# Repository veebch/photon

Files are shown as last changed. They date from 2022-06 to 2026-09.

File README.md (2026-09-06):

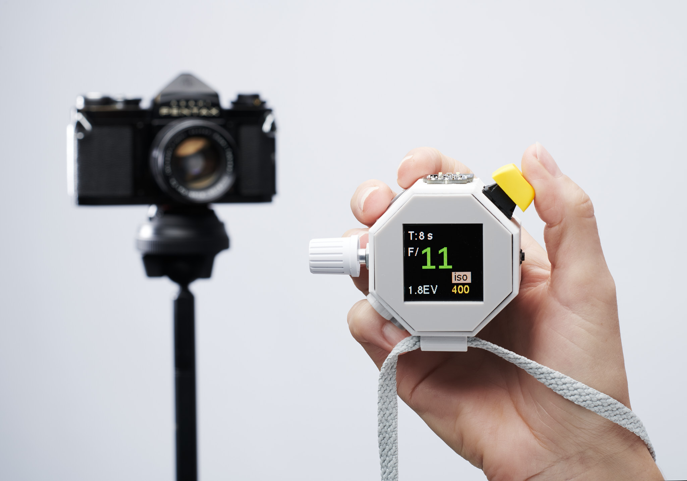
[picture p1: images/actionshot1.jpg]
Action Shot


 

# Photon: an open-source incident light meter 

Photon reproduces the some of the functionality of more expensive tools, using a few inexpensive/readily available parts. Currently it measures ambient light brightness, as well as the red, green and blue components of the light, which might allow White Balance readings in future iterations.

There is soldering involved, but don't let that put you off, [it's easy](https://www.youtube.com/watch?v=Qps9woUGkvI).

COMING SOON: Custom sensor with [Flash Mode](https://www.veeb.ch/projects/flash-aaahhh-ahhhhhh)

## Background

An incident light-meter can be an essential tool in photography (especially film photography with old cameras). The sophisticated computation baked-in to modern cameras devotes a lot of effort guessing 'how much light is falling on the subject?". If you have the option of getting to the subject and taking a reading, no guessing is required and everything becomes a lot easier. A more in-depth description in the video below:

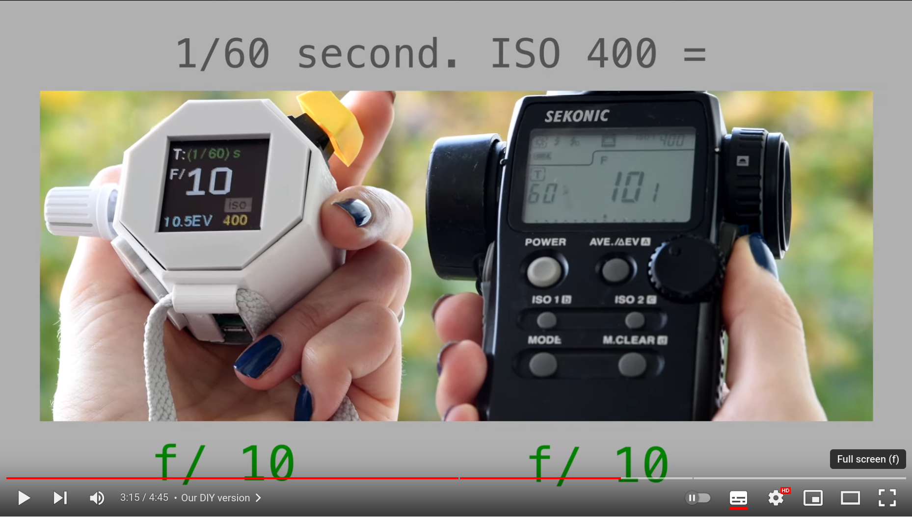
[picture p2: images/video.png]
IMAGE ALT TEXT HERE (https://www.youtube.com/watch?v=xju3yHBka7Q)


## Components

- Raspberry Pi Pico           (or Pico Lipo, so you don't need to add the separate power shim)
- OLED Screen                 ([Waveshare 128x128 full colour](https://www.amazon.de/-/en/gp/product/B07DB5YFGW/ref=ppx_yo_dt_b_asin_title_o08_s00?ie=UTF8&psc=1))
- LiPo Power shim             ([Pimoroni LiPo Pico shim](https://shop.pimoroni.com/products/pico-lipo-shim?variant=32369543086163) - only if you a using a Pi Pico)
- Rotary encoder              (adjust settings and change priority mode) ([example](https://www.reichelt.com/ch/de/entwicklerboards-drehwinkel-encoder-ky-040-debo-encoder-p282545.html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))
- Two momentary switches      (1x [keyboard switch](https://keyboardsexpert.com/types-of-keyboard-switches/) and 1x **6x6mm** microswitch to measure light and set iso adjust mode respectively)
- Light Sensor                ([Pimoroni BH1745](https://shop.pimoroni.com/products/bh1745-luminance-and-colour-sensor-breakout?variant=12767599755347))             
- LiPo/LiIon battery

# Assembly

## Hardware

If you're using one, solder the power shim to the pico following the Pimoroni instructions. Connect the Lipo/LiIon battery to the shim. 

Then connect the rest of the components to the GPIO pins as described in the tables below. (**VCC and GND are also connected to the pico for all except the switch**) 

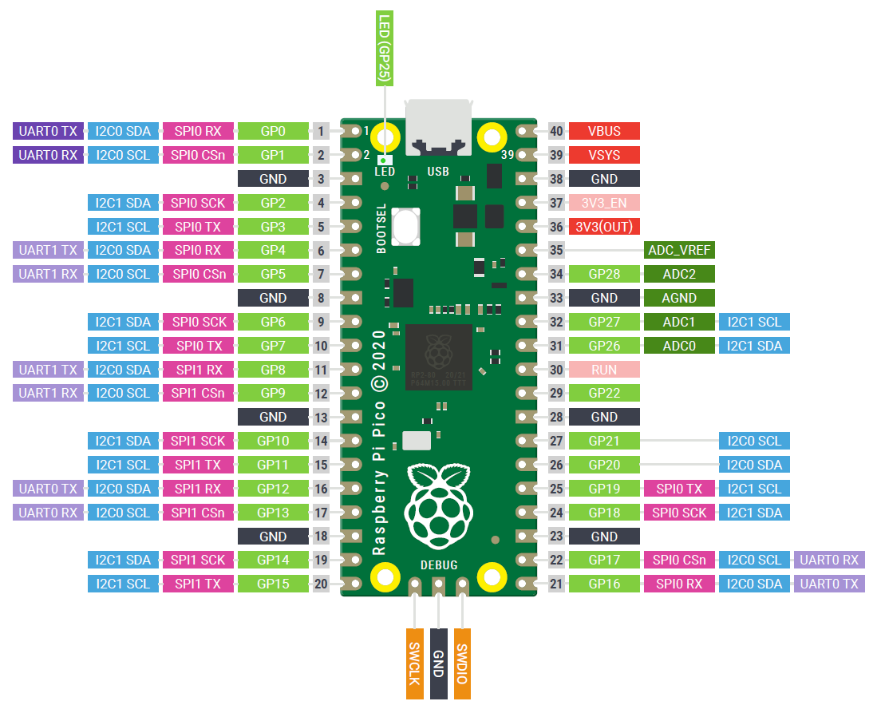
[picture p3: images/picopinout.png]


### Light Sensor

| [Pico GPIO](https://www.elektronik-kompendium.de/sites/raspberry-pi/bilder/raspberry-pi-pico-gpio.png) | BH1745 |
|---|---|
| 4 | SDA  |
| 5 | SCL  |

### OLED

| [Pico GPIO](https://www.elektronik-kompendium.de/sites/raspberry-pi/bilder/raspberry-pi-pico-gpio.png) | OLED | Pin Number |
|---|---|---|
| 19 | DIN/MOSI  | 25 | 
| 18 | CLK/SCK  | 24 |
| 17 | CS  |  22 |
| 20 | DC  |  26 |
| 21 | RST  | 27  |

### Rotary Encoder:

| [Pico GPIO](https://www.elektronik-kompendium.de/sites/raspberry-pi/bilder/raspberry-pi-pico-gpio.png) | Rotary Encoder |
|---|---|
| 6 | CLK |
| 7 | DT |
| 8 | SW |

### The Two Switches

Connect one end of the switch to GND, and the other to:

| [Pico GPIO](https://www.elektronik-kompendium.de/sites/raspberry-pi/bilder/raspberry-pi-pico-gpio.png) | Switches |
|---|---|
| 15 | Measure (Keyboard Switch) |
| 22 | ISO (6x6mm switch)  |

### Enclosure Assembly

Once you've tested that things are working, squeeze the parts into an enclosure. If you have access to a 3D printer, there are stl files in the [cases](/cases) directory.

## Software

Download a `uf2` image from the [Pimoroni github repository](https://github.com/pimoroni/pimoroni-pico/releases) and install it on the Pico according to the instructions. You need to use the Pimoroni image to be able to use Pimoroni drivers for the light sensor.

Clone this repository to your computer using the commands (from a terminal):

```
cd ~
git clone https://github.com/veebch/photon.git
cd photon
```

Connect the Pico with a data-capable USB cable in normal MicroPython mode. On macOS or Linux, prepare the local upload environment once:

```sh
python3 -m venv .venv
.venv/bin/python -m pip install -r requirements-dev.txt
```

Upload Photon and restart the Pico:

```sh
.venv/bin/python tools/upload_pico.py
```

The uploader normally detects the only connected MicroPython board. If more than one serial device is connected, select the Pico explicitly:

```sh
.venv/bin/python -m mpremote devs
.venv/bin/python tools/upload_pico.py --port /dev/cu.usbmodem101
```

Linux port names commonly look like `/dev/ttyACM0`. Close Thonny, serial monitors, and other programs using the Pico before uploading. To inspect the commands without changing the board, add `--dry-run`.

All required files are copied to the Pico, which is then soft-reset so `main.py` starts. It will also autorun after later power cycles.

## Using the Light Meter 

A tutorial on getting the most out of your new meter is in the [docs](/docs) section. 

## Press

### German 
- https://heise.de/-9611848

## Contributing to the code

If you look at this, find it interesting, and know you can make it better then please fork the repository and use a feature branch. Pull requests are welcome and encouraged... in a nutshell:

1.    Fork it
2.    Create your feature branch (git checkout -b feature/fooBar)
3.    Commit your changes (git commit -am 'Add some fooBar')
4.    Push to the branch (git push origin feature/fooBar)
5.    Create a new Pull Request

If that all looks a bit too programmy, and if you have some photography expertise that you think could be embedded in the code then raise an issue on GitHub or [contact us](https://www.veeb.ch/contact).

## Licence

GNU GENERAL PUBLIC LICENSE Version 3.0

# Appendix
## Calculation of Values

The simple calculations that lead to a reading are based on the Wikipedia entry on [exposure value](https://en.wikipedia.org/wiki/Exposure_value).

The [illuminance](https://en.wikipedia.org/wiki/Illuminance) returned by the Pimoroni BH1745 ( $L$ ) is converted to an exposure value ( $E_v$ ) for ISO 100 using

$$E_v=\log _2  {{L} \over {C}},$$

where $C$ is the light meter [calibration constant](https://en.wikipedia.org/wiki/Light_meter#Calibration_constants).

This exposure value is then adjusted to an Exposure value for the chosen ISO ( $E_{ISO}$ ) using

$$E_{ISO}=E_v + \log_2 {{ISO}\over{100}}.$$

Then, depending on the priority on the light meter, the remaining value is calculated using

$$t = {{N^2} \over {2^{E_{ISO}}}}$$  

or

$$N = \sqrt{t 2^{ E_{ISO}}}$$

where $t$ is shutter speed and $N$ is f-stop. The value is then rounded to the nearest nominal value and displayed on the screen.

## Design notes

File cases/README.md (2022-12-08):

# Cases

A place for the printable files to make your own case. Feel free to contribute your own designs/ refinements by [forking the respository](https://docs.github.com/en/get-started/quickstart/fork-a-repo). If possible, supplement your files with photos of how the internals fit together. Each design is listed as a subdirectory

**NB** The files in the directory `Original` are only usable with some filing of corners of the pcb that the OLED screen fits onto. Enthusiasm for a frame meant some measurements were overlooked.

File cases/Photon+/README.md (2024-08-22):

# Photon+

A place for the case elements for the flashmeter version that uses the [new sensor](https://www.veeb.ch/projects/flash-aaahhh-ahhhhhh). The fast sensor allows for the addition of a flash modem while still being able to perform the same metering as the original design. 

The case borrows heavily from the PicoLipo case. The new sensor now sits inside the case and the case is much more sealed than the first version.

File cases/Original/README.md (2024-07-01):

# Original Case

This is the original design featured in the video. It is less sophisticated than more recent additions. It was made high on enthusiasm and low on skill.

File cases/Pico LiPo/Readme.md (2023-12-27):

# Pimoroni Pico LiPo case with Lumisphere

This case is completely redesigned, but very similar to the original firstframe.stl design and only slightly larger.

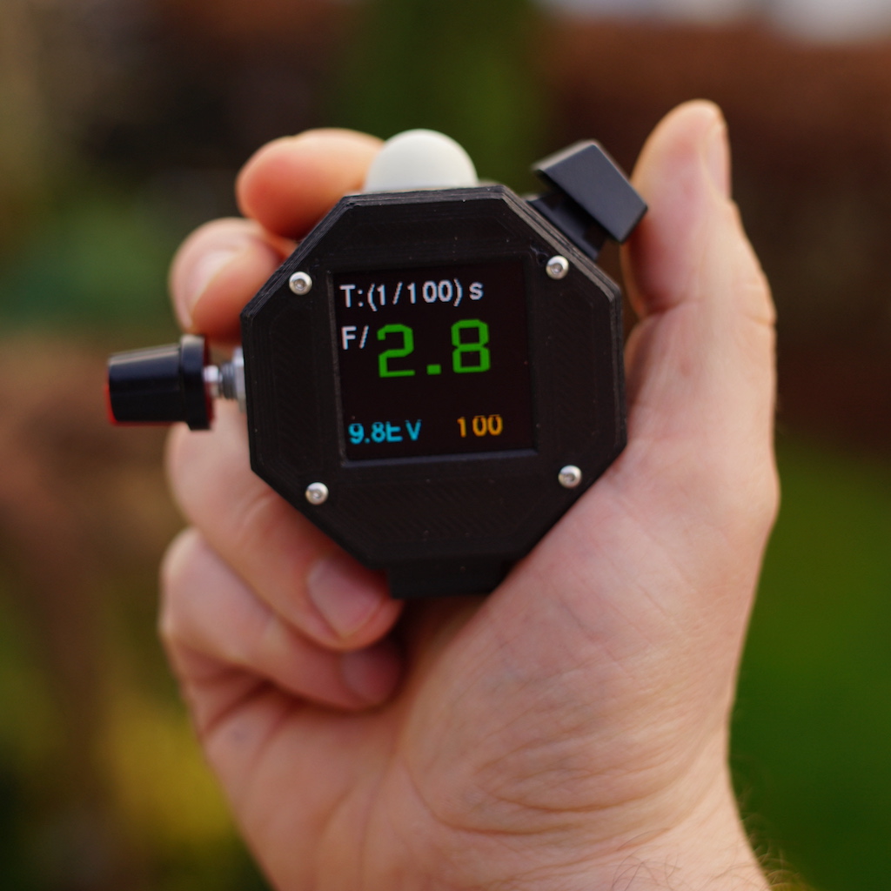
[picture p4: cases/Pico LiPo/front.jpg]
Front


### Author
- [Frederik Kemner](https://github.com/040medien)

### These were my requirements:
- Add a dedicated lumisphere dome and move the [Pimoroni BH1745](https://shop.pimoroni.com/products/bh1745-luminance-and-colour-sensor-breakout?variant=12767599755347) light sensor board inside the case for protection.
- Make the [Waveshare 128x128 full color](https://www.amazon.de/-/en/gp/product/B07DB5YFGW/ref=ppx_yo_dt_b_asin_title_o08_s00?ie=UTF8&psc=1) display fit without needing to sand off the corners.
- Use the [Pimoroni Pico LiPo](https://shop.pimoroni.com/products/pimoroni-pico-lipo?variant=39386149093459) board, since you don't have to use a separate LiPo Shim, it supports USB-C and has its own power button.
- Keep the case small. This required using a smaller [820mAh lipo battery](https://www.amazon.de/gp/product/B082152887).
- Make all parts printable without supports.

### Notes:
- The lumishpere and the power button were printed with a resin SLA printer. It might work with FDM, but I haven't tried.
- The lumisphere will make sure that you measure the ambient light instead of the reflected light.
- In my case I had to add a 1.5 stop correction to the measurement since there is some light loss due to the lumisphere. This is done by changing `evcorrection` to `1.5` in `main.py`.

### Assembly instructions:
- You need 4 M2 screws for the top, 4 M3 screws for the bottom, 2 M2.5 screws for the microswitch bracket and 2 M2 screws for the lumishpere.
- First solder on the wires to the components and then install the microswitch and the lumishpere before everything else. These are tricky. Next the [rotary encoder](https://www.berrybase.de/drehregler/rotary-encoder-mit-breakoutboard) with the connectors facing towards the Pico. I heated the little prong to seat it into the case. I had to bend the connectors and solder on the wires since dupont connectors didn't fit into the case anymore. I used some double sided tape to stick on the battery. The Pico LiPo just slots in and gets held in by the back part.
- The power button is a bit fiddly. I used a tiny ring of soft insulation foam between it and the case so it doesn't drop down and get jammed.
- The power button guard has to be glued on. It prevents the meter from accidentally coming on when bumped in your camera bag.
- I soldered on the connections to the top side of the Pico since I didn't want any pointy solder blobs pierce the lipo below.

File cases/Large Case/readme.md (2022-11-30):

# Large Case for Photon

Design based on the first case with cutouts for a rotary encoder, a tactile button and the light sensor on top. It has room for all of the cables, a frame on the bottom for the Pico to snap into and a 2000 mAh battery. The screen can be secured to the lid with M2*12 screws and nuts. The case also has a screwdriver slot for easy lid opening. 

### Parts used:

- Raspberry Pi Pico W
- [Pimoroni LiPo Pico shim](https://shop.pimoroni.com/products/pico-lipo-shim?variant=32369543086163)
- [Waveshare 128x128 full colour](https://www.amazon.de/-/en/gp/product/B07DB5YFGW/ref=ppx_yo_dt_b_asin_title_o08_s00?ie=UTF8&psc=1)
- [Tactile Button](https://www.amazon.de/-/en/gp/product/B07XWYHPZH/ref=ppx_yo_dt_b_search_asin_title?ie=UTF8&psc=1) (Opening: 6.2 mm x 6.2 mm)
- [Rotary Encoder](https://www.amazon.de/-/en/gp/product/B07SV5HHM5/ref=ppx_yo_dt_b_search_asin_title?ie=UTF8&psc=1) (Opening 7 mm)
- [Pimoroni BH1745](https://shop.pimoroni.com/products/bh1745-luminance-and-colour-sensor-breakout?variant=12767599755347)




*Version without the chord attachment*

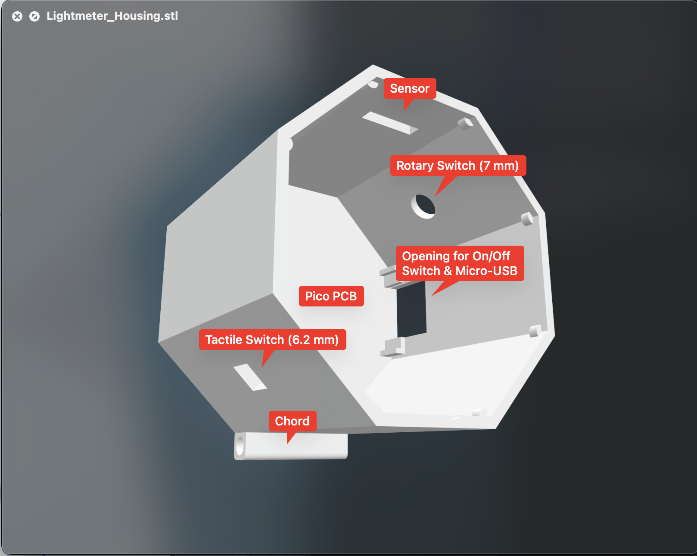
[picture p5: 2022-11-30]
cases/Large Case/SCR-20221101-i3s.png

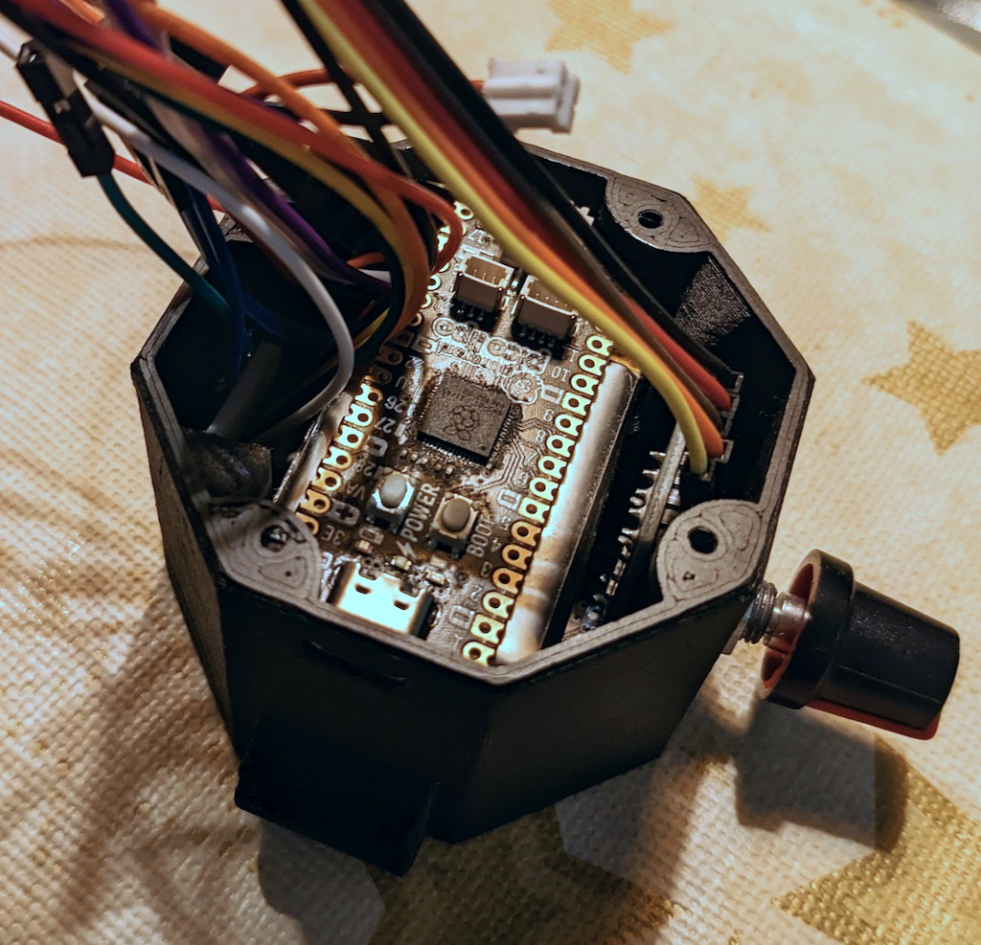
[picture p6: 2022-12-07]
cases/Pico LiPo/inside.jpg

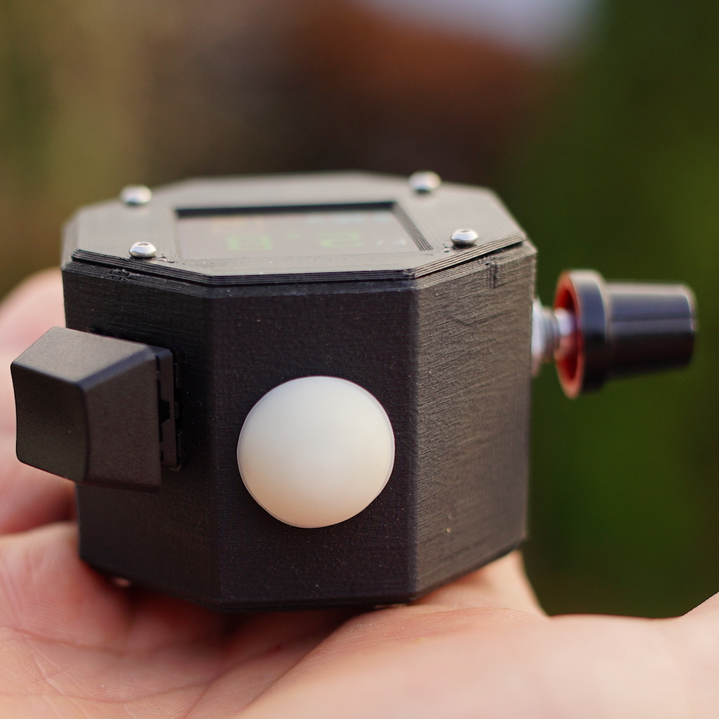
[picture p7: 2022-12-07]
cases/Pico LiPo/top.jpg

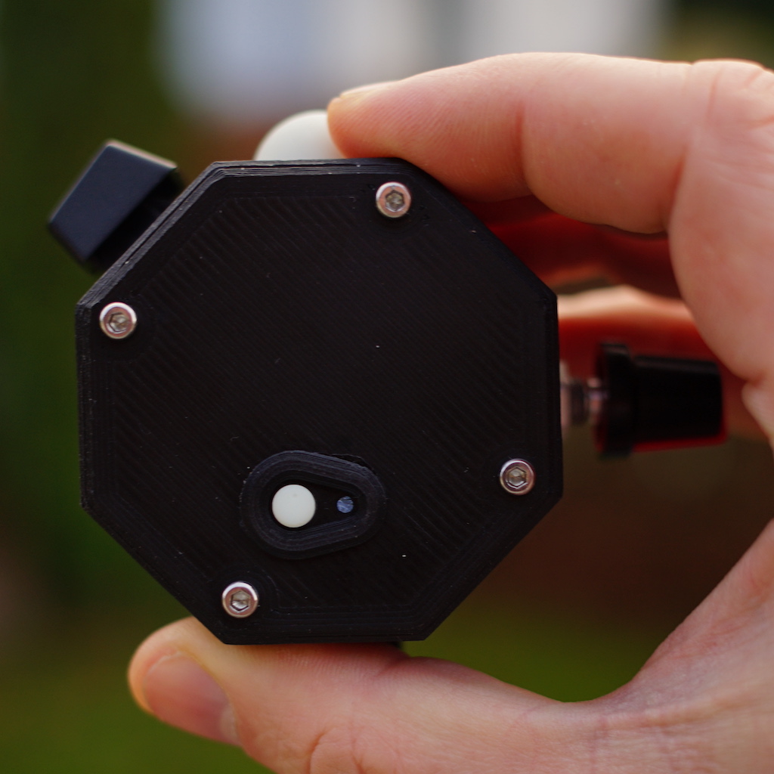
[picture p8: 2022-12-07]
cases/Pico LiPo/back.jpg

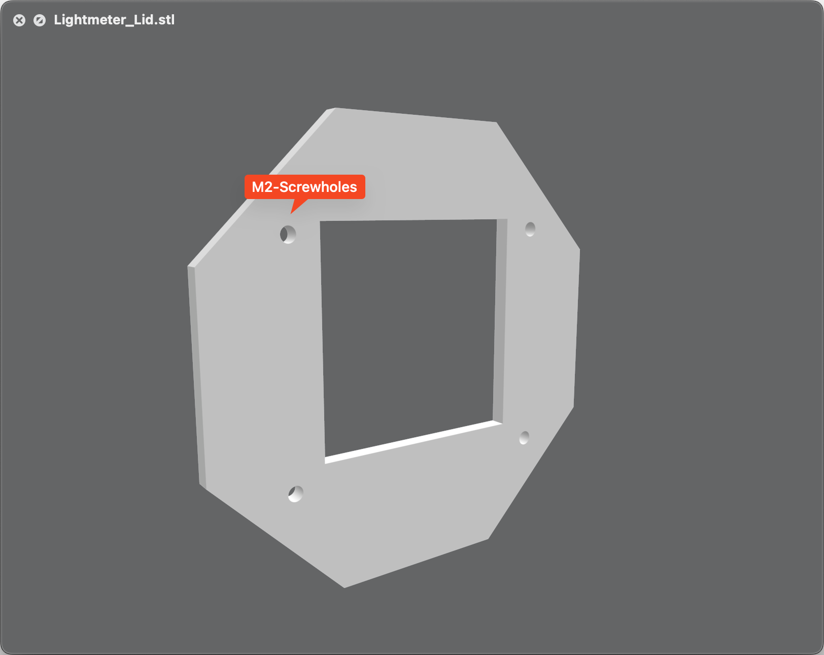
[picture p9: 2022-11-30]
cases/Large Case/SCR-20221101-i94.png

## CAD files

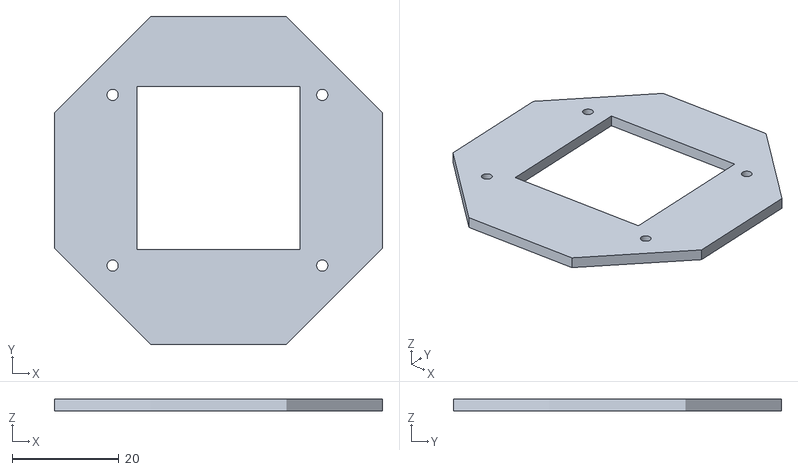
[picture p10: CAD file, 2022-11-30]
cases/Large Case/Lightmeter_Lid.stl
61.5 x 61.5 x 2.20

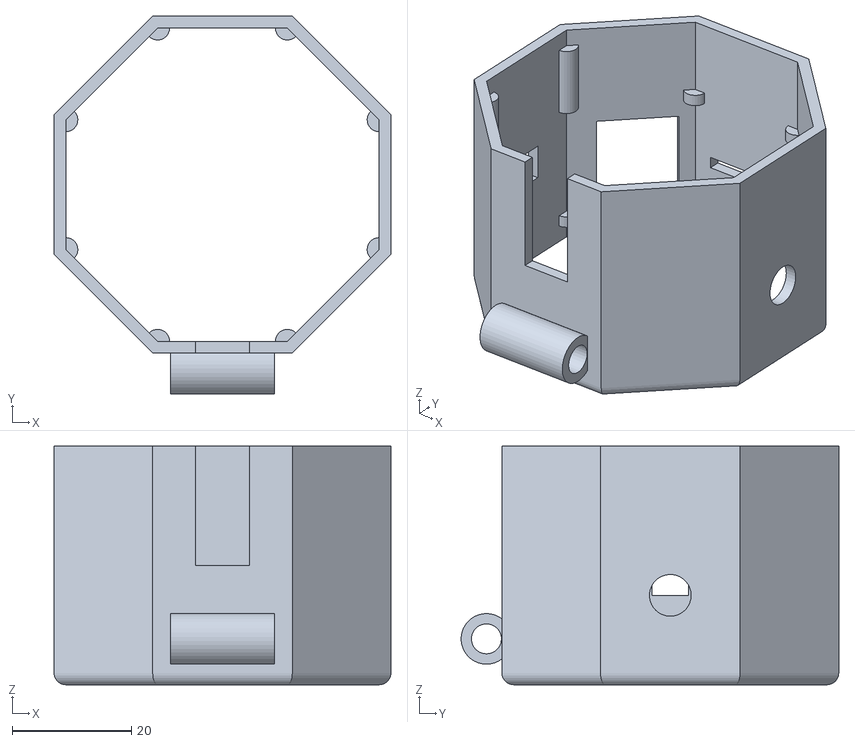
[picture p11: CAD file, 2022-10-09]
cases/Original/firstframe.stl
56.5 x 63.3 x 40.0

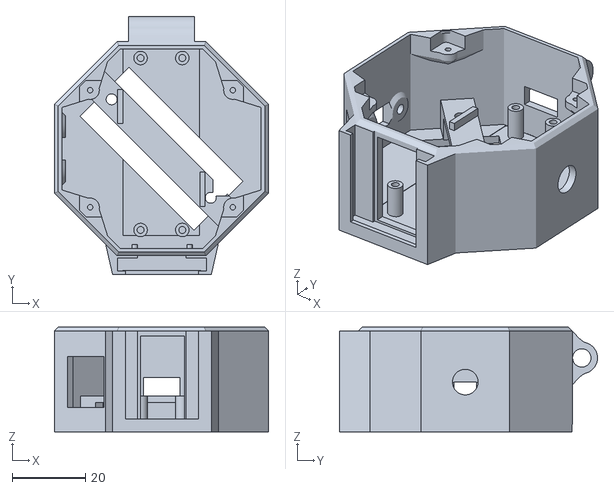
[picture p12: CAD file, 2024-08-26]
cases/Photon+/case.stl
58.5 x 70.5 x 28.6

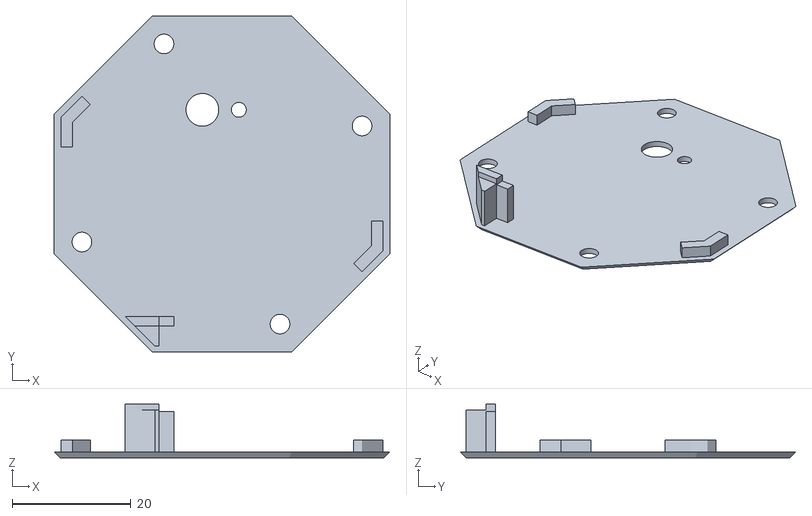
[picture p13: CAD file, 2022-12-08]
cases/Pico LiPo/back.stl
56.5 x 56.5 x 9.00

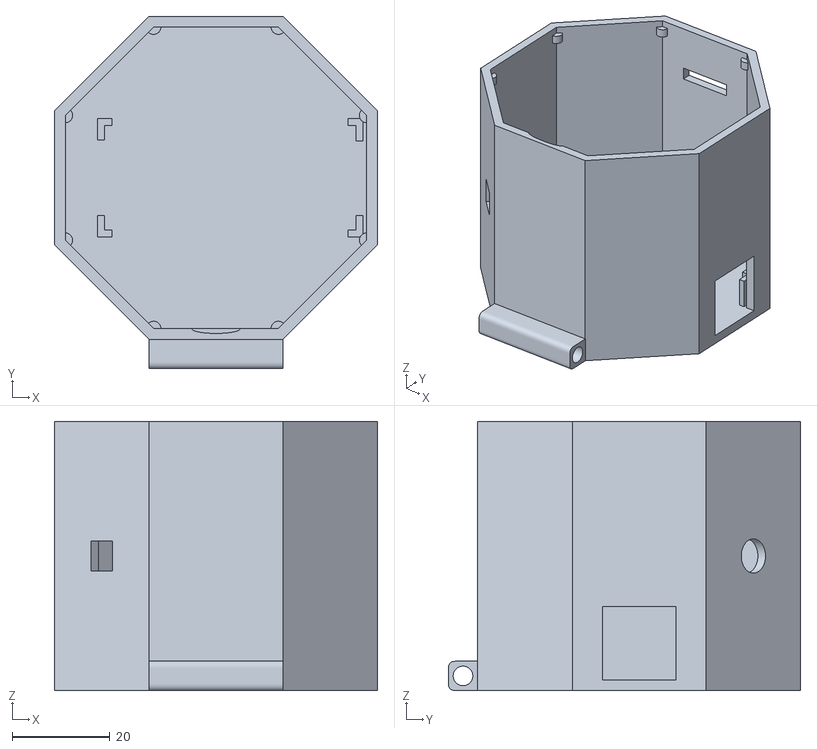
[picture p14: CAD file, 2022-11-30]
cases/Large Case/Lightmeter_Housing.stl
66.0 x 72.0 x 55.0

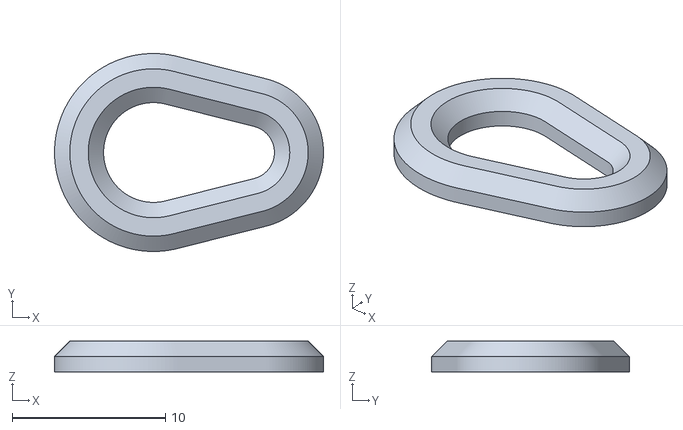
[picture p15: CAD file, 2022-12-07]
cases/Pico LiPo/power button guard.stl
17.5 x 12.9 x 2.00

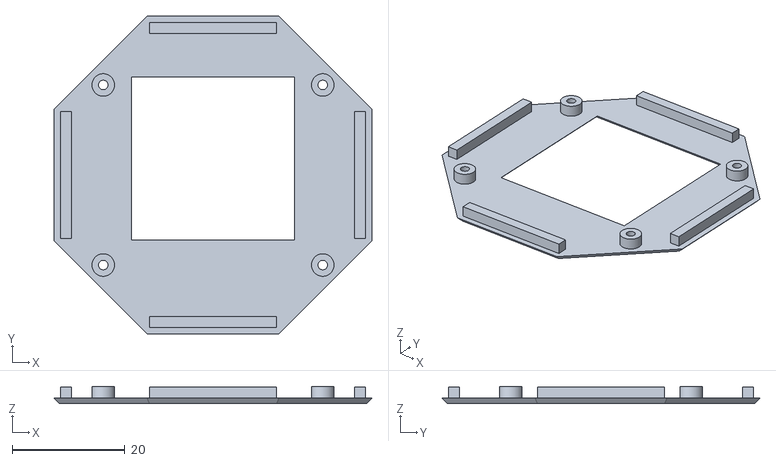
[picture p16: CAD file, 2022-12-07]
cases/Pico LiPo/front.stl
56.5 x 56.5 x 3.10

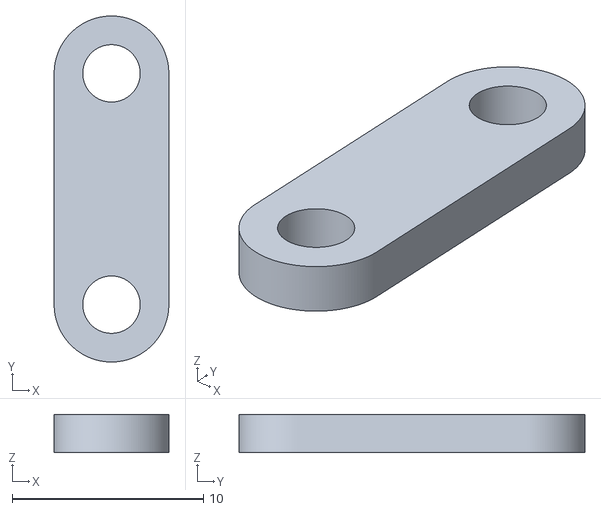
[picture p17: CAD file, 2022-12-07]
cases/Pico LiPo/microswitch bracket.stl
6.00 x 18.1 x 2.00

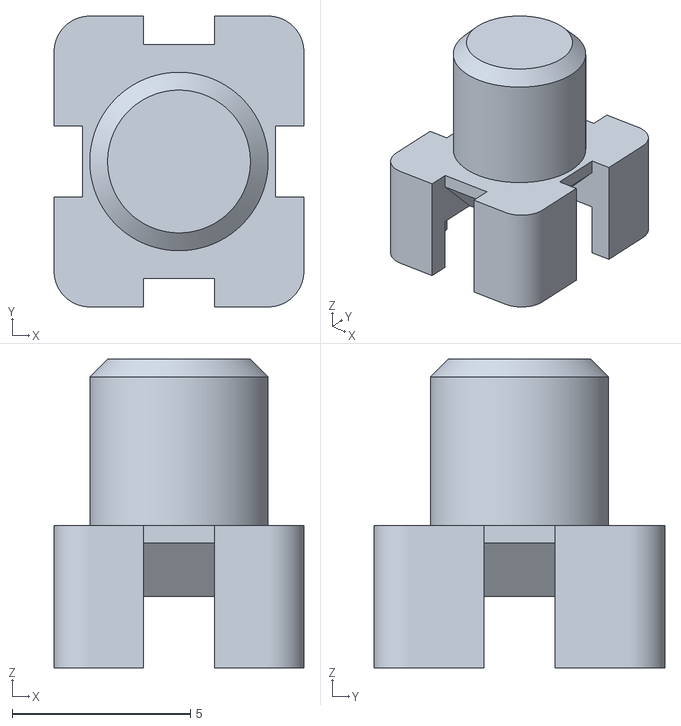
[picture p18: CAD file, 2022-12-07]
cases/Pico LiPo/power button.stl
7.00 x 8.15 x 8.66

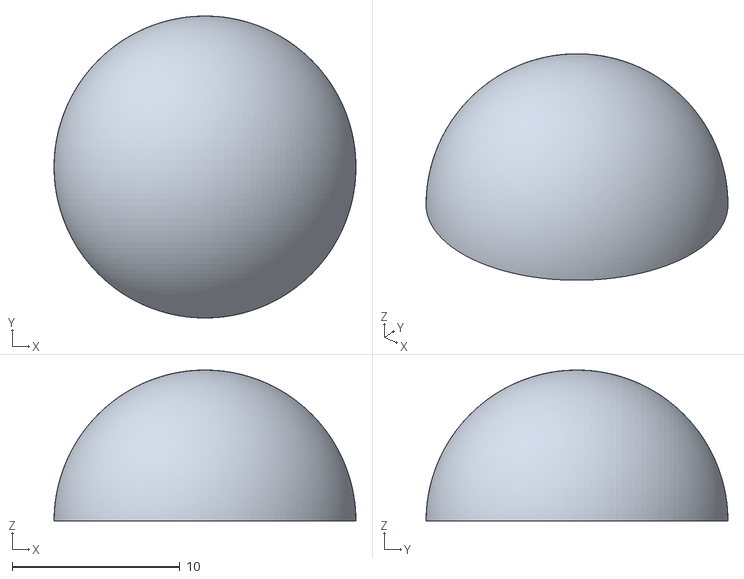
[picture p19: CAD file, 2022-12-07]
cases/Pico LiPo/lumisphere.stl
18.0 x 18.0 x 9.00

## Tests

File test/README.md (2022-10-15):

## Testing

Insert plots comparing results from photon with consumer meters and a Nikon D850 and a grey card.

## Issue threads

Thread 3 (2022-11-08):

required files result in error

jonyv0992, 2022-11-08:
After the update to the read me file the last step of installing the files to the pico result in an Error: Invalid value for each of the commands. Could the files be uploaded to the pico using Thonny?

veebch, 2022-11-08:
There are a few things you could use: rshell, ampy or thonny. In my experience, ampy was the most reliable and involved least effort.
It sounds like your ampy installation might be playing up. Try looking at the linked guide on the readme and see if the commands listed in the readme make sense.

veebch, 2022-11-09:
(specifically, check the port name... I've updated the readme to try to be clearer)

Closed 2022-11-10.

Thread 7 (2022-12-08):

im missing something

Stefanvoor, 2022-12-08:
Hi, im pretty new to this sort of thing and running into an issue.
when i run de code in thonny i get an error, name 'ssd' isn't defined.
am i doing something wrong here or is there something im not seeing, being a novice at this?

i am using a pico lipo board with  pimoroni-picolipo_16mb-v1.19.10-micropython.uf2

>>> %Run -c $EDITOR_CONTENT
Traceback (most recent call last):
  File "<stdin>", line 195, in <module>
  File "<stdin>", line 24, in splash
NameError: name 'ssd' isn't defined
>>>

veebch, 2022-12-09:
Welcome aboard :)

It looks like the file that defines ssd might not be loaded onto the pi? Is the OLED screen connected?

Stefanvoor, 2022-12-09:
Yes the Oled is connected, when i run gui\demos\aclock.py it seems to be working. i get a clock on the display when its running

veebch, 2022-12-09:
that gets ssid from a different place...... can you check that drivers/ssd1351/ssd1351_16bit.py is on the pico?

Stefanvoor, 2022-12-09:
they are indeed on the pico

veebch, 2022-12-09:
Looking at the code it looks like there is an issue with the sensor that means that you've found a bug.

Stefanvoor, 2022-12-10:
yes, its working perfectly over usb now, but when i power it on via a lipo its not running. the power light is on but the screen isnt coming up.

veebch, 2022-12-10:
Progress!

I've not encountered the problem with the lipo. I seem to recall that if you power it on via the lipo then you can still connect to thonny over usb. So you could run it interactively to get a better idea of the issue.

veebch, 2022-12-13:
Closing so you can add the specific LiPo issue, in the hope that someone can help

Closed 2022-12-13.

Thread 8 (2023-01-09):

Doesn't seem to do anything

mm-dockery, 2023-01-09:
Hello,

Any tips on troubleshooting an issue where the Pi doesn't seem to have any activity? I've connected the hardware as shown, and loaded the software as directed, but when I power on I see no activity on the OLED or any of the associated LEDs. Where would I look to figure out what the problem is? Unfortunately, I am not familiar with Python

veebch, 2023-01-09:
Run it interactively using Thonny. That way you'll see messages as the code runs.

90 percent of the time, it's the wires. So after you've ran the code on Thonny, check your connections.

Good luck! (Added Troubleshooting guide to the 'Do' list....)

Closed 2023-01-09.

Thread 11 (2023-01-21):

No display output

iamyd, 2023-01-21:
After assembled everything, there are no display. Then I thought it was issue with my solder, I re did all my soldering, still the same issue. I attempted to troubleshot using Thonny, the main.py ran without any error message. I decided to order a replacement screen, still nothing shows up. My multimeter shows the display is getting 3.3 volt, and the wiring connection is connect to the pico lipo. I attempted to write a hello world using the diver in the repo, still nothing shows up. Any recommendation on what to try next?

veebch, 2023-01-21:
That sounds annoying.

 Is the screen the exact same model?

I would try to get it working on a breadboard while debugging.

OLEDs look like they are doing nothing until an image is sent to them. Double check the gpio pins you're using.

iamyd, 2023-01-21:
It is the exactly same waveshare oled screen. I guess the bread board will be helpful to debug.

The Pico is working too, the micro python works well. I checked again on the pin and even read the oled manual.

In the instruction, it said CLK is connected to clock data input, but we connected to ground, does it means we don’t use clock?

veebch, 2023-01-21:
GPIO 18 on the diagram... not pin number 18 (which is gnd)

iamyd, 2023-01-21:
Issue found, thank you so much @veebch!

I connected the all GPIO pin to the regular pin. I am new to this DIY world, if would be helpful to also mark the pin number, for the pico pi.

veebch, 2023-01-21:
I've added the pin numbers to the OLED table in the readme. I didn't add them to all the tables because hopefully including them in one table only will make people see that they are two different notations.

Well done on being so tenacious!

Closed 2023-01-21.

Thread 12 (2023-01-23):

Pico Lipo Battery Level Shows -185% when startup

iamyd, 2023-01-23:
When I am starting the Photon on the splash screen it will show -185% (Sometime -186%), however if I am reading from the Thonny it will display the correct percentage. When I am debugging from Thonny, it will shows the correct voltage on screen as well. Have you experience it before?

I am trying to googling it, but it doesn't seems to go anywhere. In the main.py, the power management code is the same as the example pimoroni provided. Everything else works perfectly, what should I try to debug next?

veebch, 2023-01-23:
These are the few lines in the code that refers to that number

full_battery = 4.2                  # these are our reference voltages for a full/empty battery, in volts
empty_battery = 2.8                 # the values could vary by battery size/manufacturer so you might need to adjust them

voltage = vsys.read_u16() * conversion_factor
percentage = 100 * ((voltage - empty_battery) / (full_battery - empty_battery))

A negative value means that  Voltage < Empty battery. If that battery is at 100 percent then you just need to tweak the parameters a bit. If you've not changed anything then (Voltage - 2.8) / 1.4 = -1.86, so your battery is at 2.8 - 1.4 * 1.86 , about .2V? That see,s low, but my mental arithmetic may be off :)

veebch, 2023-01-23:
The other number that is important is conversion factor, maybe the Pico Lipo reads volatage differently to the shim that was originally used?

iamyd, 2023-01-24:
The conversion factor looks right, here is an example from pimoroni. If I try to debug this pico, the reading is also correct.

iamyd, 2023-01-24:
This is when I am trying to debug using Thonny.
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

veebch, 2023-01-28:
so that would suggest first setting full _battery as **2.8** ((2/3)*4.2),  and change empty_battery to **1** and you'd want to make a note of the percentage just before the power dies and then use that value to determine how to adjust that to 0 percent by calculating the correct value of empty_batttery

There seems to be something amiss for that conversion factor though, the voltage reading when plugged in to usb should be 5v(?) or maybe 3.3v....... anyway, definitely not 2.8v, which is what it needs to be to give 67 percent.

iamyd, 2023-01-30:
If I meeting the full_battery to 2.8 and empty battery to 1, then the power level is -45%, which still doesn't seem right. You are right about the conversion factor, I think there might be an issue there. If I use 4 * 3.3 / 65535 as my conversion factor, I can get 100% when I am debugging from Thonny

iamyd, 2023-01-30:
If I use the conversion factor of 74.5 * 3.3 / 65535, my fully charged battery will shows 100%, according to some math calculations, the vsys.read_u16() is only reading 1320.63. If we assume the 4 * 3.3 / 65535 is the correct conversion factor (vsys.read_u16() read 24565 when plug into USB which should be 5 volt). That being said, my battery voltage is only 0.28 volt when fully charged which doesn't seems to be correct.

veebch, 2023-01-30:
Can you read the voltage directly off the battery using a multimeter?

iamyd, 2023-01-31:
It is 3.7 volt currently, a fellow redditor ([ToLoveSome](https://www.reddit.com/user/ToLoveSome) also having issue with the battery level. He recommended to read the voltage 10,000 times and for some reason it worked.

I tested and confirmed it worked, then it get me to think when it is reading 10,000 times, it is just reading it again and again. Why don't we just let it wait for a period of time, I tested 0.1 sec all the way to 1 sec in an increment of 0.1 sec. I found that after 0.3 sec, the voltage display correctly, it shows 3.7 volts which is the spec of my battery.

After reading the battery specs, I found that the overcharge protection voltage is 4.28 V, and the overdischarge protection voltage is 3.0 V. I think the battery level need to be adjusted per battery.

veebch, 2023-02-01:
Merged.... closing :)

Closed 2023-02-01.

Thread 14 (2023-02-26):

Calibration Constant?

polygonfuture, 2023-02-26:
Hi there,

I see your calibration constant is set to 15.   Why chose 15 over typical regular constants such as 12.5 and 14?  Could you tell me about this value choice?  (Newbie here and trying to understand this more)

veebch, 2023-02-26:
The original is in the code (I think). I was thinking about making this something that can be set via the UI for people who use different sensors/cases. The sunny 16 rule for direct sunlight would be a good method for those who don't have a second meter to check against.

Anyway, I digress. Short answer: it's in the code.

Closed 2023-11-11.

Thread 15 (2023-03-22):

Rotate Display

polygonfuture, 2023-03-22:
Hi there,

I am building a custom case and pcb to house all the components in a different form factor.  Unfortuantely the design requires me to rotate the display 180.   I'm having trouble finding examples of how you'd rotate the display 180 with micro-python.  Have you looked into this before or have a solution?

veebch, 2023-03-22:
Not looked into it, but I would see if I could rotate the framebuffer 180 degrees. I'll look into it....

veebch, 2023-03-31:
Did you make any progress on this?

polygonfuture, 2023-04-18:
I solved the issue by sending a hardware command SET-REMAP and a corresponding 7bit byte command to the SSD1351 chipset.

In this case its two lines that are added to the ssd1351_16bit.py file just after we send these byte commands for initializing the SSD1351 in the` def __init__` section:

```
        # See above comment to explain this allocation-saving gibberish.
        self._write(b'\xfd\x12\xfd\xb1\xae\xb3\xf1\xca\x7f\xa0\x74'\
        b'\x15\x00\x7f\x75\x00\x7f\xa1\x00\xa2\x00\xb5\x00\xab\x01'\
        b'\xb1\x32\xbe\x05\xa6\xc1\xc8\x80\xc8\xc7\x0f'\
        b'\xb4\xa0\xb5\x55\xb6\x01\xaf', 0)
```

```
        self._write(b'\xA0',0)  #SET REMAP COMMAND
        self._write(b'\x76',1)  #SEND 7 BIT COMMAND IN HEX FORMAT THAT FLIPS DISPLAY.  IN BINARY:  01110110
```

First line tells the chipset we are going to make changes to the SET REMAP values.
Second line sets a 7bit value that changes 6 different settings on the chipset.

There is value table I used to know what to set these to in [this datasheet ](https://www.waveshare.com/w/upload/a/a7/SSD1351-Revision_1.5.pdf)on page 32.   The A[1] bit is the value swaps the column address, and A[4] bit is how we swap the row / scan order.

veebch, 2023-04-18:
Woah.... that's lower level than I was thinking.

polygonfuture, 2023-04-18:
I tried for 5 minutes to flip the framebuffer in the show() command and gave up and just found that command in the datasheet.  haha

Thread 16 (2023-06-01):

BH1750 instead of BH1745

Mojojojooo, 2023-06-01:
Hi, I'm planning to build this and currently BH1745( Colour and luminance sensor) has been unavailable for a long time. Since the calculation part just shows that luminance is used. Can BH1750 which is just a luminance sensor be used instead of BH1745 ?

Mojojojooo, 2023-06-01:
How are the RGB values being used for calculation? As 1750 won't have RBG values any idea how can we bypass it ?

veebch, 2023-06-01:
They are only used in determining the colour of the EV reading. It should be easy to bypass.

veebch, 2023-06-05:
I would just set it to white (255,255,255)

polygonfuture, 2023-06-21:
@Mojojojooo BH1745 is not unavailable.

Pimoroni keeps it in stock regularly:  https://shop.pimoroni.com/products/bh1745-luminance-and-colour-sensor-breakout?variant=12767599755347

Mojojojooo, 2023-06-21:
@polygonfuture I mean to say it's hard to get it in India. So I was looking for an alternative.

veebch, 2023-12-19:
No one chipped in, but I made an alternative. I'll share it as soon as it's ready

[preview](https://www.veeb.ch/projects/flash-aaahhh-ahhhhhh)

Closed 2023-12-19.

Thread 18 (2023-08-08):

Stupid noob question

GitGitKangaroo, 2023-08-08:
Hi. I have zero Python experience and was interested in trying this as a first build. If I attempt to do this with qwiic connectors rather than soldering, will I need to make changes to the code?. Sorry, I'm sure that's a really dumb question but I've no idea how this works.

veebch, 2023-08-08:
Not dumb at all.

I've not used qwiic connectors, so I will let someone else provide an answer. My first impression is that you might end up using different pins to talk to the hardware, so the code would need to be tweaked by changing the pin numbers.

Anyway, I'm making stuff up, so I'll be quiet. Good luck with the build!

Closed 2023-11-11.

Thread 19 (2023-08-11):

Don't work with me ;(

AndreScalaPT, 2023-08-11:
Hello, thank you for sharing your project with the community.
I don't see a discussion forum so I'll open as an issue, sorry.

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

So... I've followed everything... I believe.
So far, the LCD don't turn on and with the battery connected I don't have a signal in the board that is charging and don't turn on connected directily with the battery; the rest of the components I don't know how to test.

I used the pimoroni-picolipo_16mb-v1.20.4-micropython.uf2  because is the Pi that I have and uploaded the files using Thonny.

When I press the switch a light blink don't power up; if I have the Pi on and press the switch the power led only blinks once.

Help? 😅

Many thanks
🍻

veebch, 2023-08-12:
We've chatted about this on irc but I'll repeat myself here in case it's useful to anyone else.

If the sensor has problems, it will have the behaviour you describe. Try running a simple example code from pimoroni to check that it is working.

veebch, 2023-08-12:
Closing :) Wires....always wires

AndreScalaPT, 2023-08-12:
Yeess, yes, yes!
Just after soldering the cables to the sensor I was able to run everything.

Thanks @veebch 🍻

Closed 2023-08-12.

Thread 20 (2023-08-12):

Soldering still required?

BadRothenfelde, 2023-08-12:
I bought the Pico Lipo which in turn doesnt need soldering of a shim.
Do I need soldering for anything else besides the aforementioned shim?

veebch, 2023-08-12:
Does the Pico Lipo already have headers on there? I'm pretty sure that the sensor needs soldering

Closed 2023-11-11.

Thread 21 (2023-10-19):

3D-Assembly

orso7, 2023-10-19:
Is there a chance that you will offer a 3D-Assembly?
At least for the printable parts? or share the parts in a neutral solid format like STEP? I would love to build the Pico Lipo version but might try to modify the case a bit.

veebch, 2023-10-19:
You could alter it by importing it into freecad (or your chosen tool) and converting it to a mesh. I'll also look at adding the original source files to the repository.

orso7, 2023-10-19:
What program did you use to design the source files?

If not available otherwise I will probably rebuild the Pico LiPo version in Solidworks since mesh isn't fun to edit there, solids are better.

Closed 2023-10-19.

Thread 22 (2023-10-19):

RPi Pico Lipo 4/16Mb?

orso7, 2023-10-19:
Do I need the 16Mb version or is the 4Mb enough?

veebch, 2023-10-19:
4 is plenty! The pico (which it also happily runs on, only has 2

Closed 2023-10-19.

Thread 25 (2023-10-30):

Pico gets hot and starts smelling smokey when connected to battery

BadRothenfelde, 2023-10-30:
is that normal?

veebch, 2023-10-30:
No. Double check the polarity on the battery connector and the battery

BadRothenfelde, 2023-10-30:
But I physically can't connect it the other way around since the clip from the battery doesn't fit  then.

veebch, 2023-10-30:
I once had the same thing happen to me. Notice the warning (4th pic) [here](https://www.amazon.de/-/en/Battery-Lithium-Batteries-polarity-purchase/dp/B08FD39Y5R)

ryan1894, 2023-10-31:
had same issue. you can lift a plastic tab on the battery white port and pull out the pin to swap it.

BadRothenfelde, 2023-10-31:
Okay, cheers

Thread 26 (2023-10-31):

How to attach rotary encoder?

ryan1894, 2023-10-31:
My rotary encoder came without a breakout board, and according to most pictures, the middle of the 3 pins and one of the two pins are connected to ground

but I can't get my rotary encoder to output anything when connected to arduino lab for micropython

Am I supposed to connect to middle of 3 pin to VCC?

Edit: I have it working in arduino lab, but outA.value is always equal to outB.value for both directions

theyre either both 0 or both 1

For reference I am using an EC-11 rotary encoder I pulled from a previous keyboard project. It seems that the pico is checking too slow?

veebch, 2023-10-31:
I've only used them on a breakout board. The micropython.org forum might be useful

ryan1894, 2023-11-01:
wow ok looks like my gpio pint 6 and 7 were actually shorted due to bad soldering.

i had to make pin 6 and 7 both PULLUP resistors but otherwise it totally works

Closed 2023-11-01.

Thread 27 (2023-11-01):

installing to pico

illejandro, 2023-11-01:
i managed to get everything soldered and together, but i get no picture on the OLED and i also cant figure out how to install the necessary files to the pico. I have tried, Thonny, Putty, and Gitbash. Ive tried all codes provided and cant seem to figure it out. cant get the port of the pico either. what is the proper steps to install this into pico. i have no experice with code or even python.

veebch, 2023-11-01:
Have you tried ampy? https://learn.adafruit.com/micropython-basics-load-files-and-run-code/install-ampy

illejandro, 2023-11-01:
I believe I installed it but got this.
`Installing collected packages: pyserial, python-dotenv, colorama, click, adafruit-ampy
  WARNING: The scripts pyserial-miniterm.exe and pyserial-ports.exe are installed in 'C:\Users\User\AppData\Local\Packages\PythonSoftwareFoundation.Python.3.11_qbz5n2kfra8p0\LocalCache\local-packages\Python311\Scripts' which is not on PATH.
  Consider adding this directory to PATH or, if you prefer to suppress this warning, use --no-warn-script-location.
  WARNING: The script dotenv.exe is installed in 'C:\Users\User\AppData\Local\Packages\PythonSoftwareFoundation.Python.3.11_qbz5n2kfra8p0\LocalCache\local-packages\Python311\Scripts' which is not on PATH.
  Consider adding this directory to PATH or, if you prefer to suppress this warning, use --no-warn-script-location.
  WARNING: The script ampy.exe is installed in 'C:\Users\User\AppData\Local\Packages\PythonSoftwareFoundation.Python.3.11_qbz5n2kfra8p0\LocalCache\local-packages\Python311\Scripts' which is not on PATH.
  Consider adding this directory to PATH or, if you prefer to suppress this warning, use --no-warn-script-location.
Successfully installed adafruit-ampy-1.1.0 click-8.1.7 colorama-0.4.6 pyserial-3.5 python-dotenv-1.0.0
`

Not sure if im missing something

veebch, 2023-11-01:
That looks ok, other than a few warnings about the PATH. If you can't run it, then that message has the path to to executable.

illejandro, 2023-11-01:
I think i installed it but now the ampy code just sits and doesnt show any status. I also triple checked my OLED and there is no image at all, only LED light on from liposhim

veebch, 2023-11-02:
Congratulations! It's *always* the wires :)

Closed 2023-11-01.

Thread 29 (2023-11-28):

Cannot get ampy to install to Windows Powershell

BadRothenfelde, 2023-11-28:
I am trying to get the software-side of this project to work - to no avail.
I have installed Python on my Windows Laptop.
I then need to install the python package installer (pip) and only then can I install ampy and thusly the photon software.

Am I understanding this correctly from a newbs' perspective?

Thanks for the help in advance and greetings from Cologne.

veebch, 2023-11-28:
Hello Cologne!
I've not installed it on windows but what you describe sounds sensible. Have you tried WSL? https://learn.microsoft.com/en-us/windows/wsl/install. It has worked well for me in the past.

Tip:
If you're ever in a situation where there is an issue transferring files to a pico and there aren't that many files you need to make, then you always have the option of making them with Thonny. It's a bit of a hack, but it works in a pinch :)

Good luck with the build

Closed 2023-12-19.

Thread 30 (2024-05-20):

Pico Lipo case : To support or not support ?

fitaine, 2024-05-20:
Hey there, this is a question for @040medien about the printing of the lipo case.

In the Readme.md there is a part about requirements which states "Make all parts printable without supports". When I checked the stl file before printing I saw a bridge in the middle of the case.

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

It needs bridge so I was wondering :

- It is a bug in the stl file : there is no support needed here.
or
- It is a compromise to get a better print: the case need support enabled.
I suppose the latter...

Thank you so much for that project, it will be a great help for me !

fitaine, 2024-05-24:
I ended up printing it with supports. Really nice case with some nice details !

040medien, 2024-05-24:
Thank you @fitaine - on my FDM printer small bridges like this don't need supports. That said, I don't remember what the bridge was for. I might have glued a component onto it, e.g. the battery.

040medien, 2024-08-08:
Thanks @veebch - I still use my photon regularly and proudly (even though I actually have an off-the-shelf light meter). Thank you for this project!

veebch, 2024-08-08:
Glad to hear it! I'm just making some updates to it (adding a new sensor that does flash and a battery compartment). I'm using your case as my starting point.

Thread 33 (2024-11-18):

Missing STL files?

dkallen78, 2024-11-18:
I'm looking for the right STL files to use and I can't find a proper contact method. I noticed the directory for the original case is missing the top and back parts of the print. And when looking at the directory for the larger case, the STL is missing the aperture for one of the switches. I have a Pico with a LiPo shim so I can't use the LiPo case, and I have the Pimoroni sensor, not your custom one so I can't use the Photon+

veebch, 2024-11-18:
It seems I just missed you on chat. The original case is in need of an update. It used cut acrylic on the front and back. It was really just a shell and the pico lipo case had some nice elements in there.

The photon+ stuff should be going into the repo in the next couple of weeks. The moment that is done, I'll update the original case.

I recall you asking about the lumisphere. Unless you want to recalibrate the code to the sensor behind the lumisphere then you can use without.

dkallen78, 2024-11-18:
no worries! is there any chance I can fit the Pico + shim and the original
Pimoroni sensor in the Photon+ enclosure?

Thanks!

On Mon, Nov 18, 2024 at 1:29 PM VEEB Projects ***@***.***>
wrote:

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

veebch, 2024-11-19:
I used the same setup for the original so I can give it a whirl. At the very least it could form the basis of a better version that could be tweaked a little to fit everything in.

dkallen78, 2024-11-19:
That's going to be my first attempt, and i'll break out my mediocre blender
skills if I have to!

On Tue, Nov 19, 2024 at 1:46 AM VEEB Projects ***@***.***>
wrote:

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

veebch, 2024-11-19:
That's the spirit!

(feel free to add your improvements to the repository)

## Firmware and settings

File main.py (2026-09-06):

"""
  main.py - a script for making a light meter, running using a Raspberry Pi Pico
  Assumes a linear respose in brightness, calibrates from two values in a text file
  First prototype is using an OLED, rotary encoder and a pimoroni light sensor, if a strobe mode is added. This may need to change.
  The display uses drivers made by Peter Hinch [link](https://github.com/peterhinch/micropython-nano-gui)
  Tested on pico running Pimoroni uf2 pimoroni-pico-v1.19.0-micropython.uf2
    
     Copyright (C) 2023 Veeb Projects https://veeb.ch

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
    # Fonts for Writer (generated using https://github.com/peterhinch/micropython-font-to-py)
"""


import gui.fonts.freesans20 as freesans20
import gui.fonts.quantico40 as quantico40
import gui.fonts.font10 as font10
from battery import percentage_from_voltage
from gui.core.writer import CWriter
from gui.core.nanogui import refresh
from drivers.ssd1351.ssd1351_16bit import SSD1351 as SSD
from machine import Pin,I2C, SPI,ADC
import pimoroni_i2c
import breakout_bh1745
import utime
import sys
import math
import gc

def splash(string):
    wri = CWriter(ssd,freesans20, fgcolor=SSD.rgb(55,55,55),bgcolor=0, verbose=False)
    CWriter.set_textpos(ssd, 0,0)
    wri.printstring('{:.0f}%'.format(percentage))
    wri = CWriter(ssd,freesans20, fgcolor=SSD.rgb(50,50,0),bgcolor=0, verbose=False )
    CWriter.set_textpos(ssd, 90,25)
    wri.printstring('veeb.ch/')
    ssd.show()
    utime.sleep(.3)
    for x in range(11):
        wri = CWriter(ssd,freesans20, fgcolor=SSD.rgb(55-x,55-x,55-x),bgcolor=0, verbose=False)
        CWriter.set_textpos(ssd, 0,0)
        wri.printstring('{:.0f}%'.format(percentage))
        wri = CWriter(ssd,freesans20, fgcolor=SSD.rgb(25*x,25*x,25*x),bgcolor=0, verbose=False)
        CWriter.set_textpos(ssd, 55,25)
        wri.printstring(string)
        wri = CWriter(ssd,freesans20, fgcolor=SSD.rgb(50-x,50-x,0),bgcolor=0, verbose=False )
        CWriter.set_textpos(ssd, 90,25)
        wri.printstring('veeb.ch/')
        ssd.show()
    utime.sleep(.5)
    return

# interrupt handler function (IRQ) for CLK and DT pins
def encoder(pin):
    global outA_last
    global outA_current
    global counter
    # read the value of current state of outA pin / CLK pin
    try:
        outA_current = outA.value()
    except:
        print('outA not defined')
        outA_current = 0
        outA_last = 0
    # if current state is not same as the last stare , encoder has rotated
    if outA_current != outA_last:
        # read outB pin
        if outB.value() != outA_current:
            counter = -1
        else:
            counter = 1
    # update the last state of outA pin / CLK pin with the current state
    outA_last = outA_current
    return 
    
# interrupt handler function (IRQ) for measure button
def button(pin):
    global button_last_state
    global button_current_state
    global lastmeasure
    global red, green, blue
    if button_current_state != button_last_state:
        utime.sleep(.2)
        print("Measure")
        red,green, blue,lastmeasure=sensorread()
        button_last_state = button_current_state
        print(lastmeasure)
        with open('lastisoindex.txt', "w") as f:
            f.write(str(isoindex))
        f.close()
    return

# interrupt handler function (IRQ) for SW (switch) pin
def modebutton(pin):
    global modebutton_last_state
    global modebutton_current_state
    global mode
    global modes
    if modebutton_current_state != modebutton_last_state:
        utime.sleep(.2)
        print("Toggle Mode")
        index = modes.index(mode)
        index = (index + 1) % len(modes)
        mode = modes[index]
        print(mode)
        modebutton_last_state = modebutton_current_state
    return

# interrupt handler function (IRQ) for iso switch
def isobutton(pin):
    global isobutton_last_state
    global isobutton_current_state
    global isoadjust
    if isobutton_current_state != isobutton_last_state:
        utime.sleep(.2)
        isoadjust = not isoadjust
        isobutton_last_state = isobutton_current_state
    return

# read the value from the light sensor
def sensorread():
    rgbc_raw = bh1745.rgbc_raw()
    rgb_clamped = bh1745.rgbc_clamped()
    brightness=rgbc_raw[3]
    print("Clamped: {}, {}, {}, {}".format(*rgb_clamped))
    print("Bright="+str(brightness))
    try:
        EV = math.log2(brightness/calibrationconst)+evcorrection
        print(EV)
    except:
        EV = -10
    return rgb_clamped[0],rgb_clamped[1],rgb_clamped[2],EV


# Display on OLED
def displaynum(aperture,speed,iso,mode, isoadjust, lastmeasure, red, green, blue):
    # Calculate EV based on ISO for display
    Eiso= lastmeasure + math.log2(float(iso/100))
    if mode=="AmbientAperture":
        textA=SSD.rgb(0,255,0)
        textT=SSD.rgb(255,255,255)
    else:
        textT=SSD.rgb(0,255,0)
        textA=SSD.rgb(255,255,255)
    ssd.fill(0)
    wri = CWriter(ssd,quantico40, fgcolor=textA,bgcolor=0, verbose=False)
    CWriter.set_textpos(ssd, 35,20)  # verbose = False to suppress console output
    try:
        wri.printstring(str(aperture))
    except:
        wri.printstring( "err")
    wrimem = CWriter(ssd,freesans20, fgcolor=textT,bgcolor=0, verbose=False)
    CWriter.set_textpos(ssd, 5,20)
    speed=str(speed)+" s"
    wrimem.printstring(speed)
    wrimem = CWriter(ssd,freesans20, fgcolor=SSD.rgb(255,255,255),bgcolor=0, verbose=False)
    CWriter.set_textpos(ssd, 35,0)  
    wrimem.printstring("F/")
    CWriter.set_textpos(ssd, 5,0)
    wrimem.printstring("T:")
    wrimem = CWriter(ssd,freesans20, fgcolor=SSD.rgb(55,55,55),bgcolor=0, verbose=False)    
    CWriter.set_textpos(ssd,105,80)
    wrimem = CWriter(ssd,freesans20, fgcolor=SSD.rgb(255,255,0),bgcolor=0, verbose=False)
    wrimem.printstring(str(iso))
    CWriter.set_textpos(ssd,105,0)
    wrimem = CWriter(ssd,freesans20, fgcolor=SSD.rgb(red,green,blue),bgcolor=0, verbose=False) # Colour of EV Number is the RGB code from the sensor
    wrimem.printstring(str(round(Eiso,1))+"EV") 
    if isoadjust:
        box=SSD.rgb(255,0,0)
    else:
        box=SSD.rgb(100,100,40)
    wrimem = CWriter(ssd,freesans20, fgcolor=0,bgcolor=box, verbose=False)
    CWriter.set_textpos(ssd,82,80)
    wrimem.printstring(" iso ")
    battery_text = '{}%'.format(battery_percentage())
    battery_writer = CWriter(ssd,font10, fgcolor=SSD.rgb(55,55,55),bgcolor=0, verbose=False)
    CWriter.set_textpos(ssd, 0, ssd.width - battery_writer.stringlen(battery_text))
    battery_writer.printstring(battery_text)
    ssd.show()
    return

# Derive the appropriate stop value, based on the reading from the sensor and the chosen mode
def otherindex(index, isoindex, mode, lastmeasure):
    Eiso= lastmeasure + math.log2(float(isonum[isoindex]/100))
    if mode=="AmbientAperture":
        aperture=fstops[apertureindex]
        t= (float(aperture)**2)/(2**Eiso)
        #print(t)
        derivedindex = min(range(len(sspeed)), key=lambda i: abs(eval(sspeed[i])-t))
    elif mode=='AmbientShutterSpeed':
        speed=sspeed[speedindex]
        #print(eval(speed))
        N = math.sqrt(eval(speed)*2**(Eiso))
        #print(N)
        derivedindex = min(range(len(fstops)), key=lambda i: abs(float(fstops[i])-N))
    return derivedindex

    
# Hardware ################################################################################################
try:
    LIGHTSENSOR = {"sda": 4, "scl": 5}
    I2C = pimoroni_i2c.PimoroniI2C(**LIGHTSENSOR)
    bh1745 = breakout_bh1745.BreakoutBH1745(I2C)
    bh1745.leds(False)
except:
    print("Check the sensor. An exception occurred") # A visual cue that therehas been an issue with the sensor setup

# Pins Setup
pdc = Pin(20, Pin.OUT, value=0)                       # OLED DC
pcs = Pin(17, Pin.OUT, value=1)                       # OLED CS
prst = Pin(21, Pin.OUT, value=1)                      # OLED RST
psck = Pin(18)                                        # OLED SCK
pmosi = Pin(19)                                       # OLED MOSI
switch = Pin(15, mode=Pin.IN, pull = Pin.PULL_UP)     # inbuilt switch on the rotary encoder, ACTIVE LOW
modeswitch = Pin(8, mode=Pin.IN, pull = Pin.PULL_UP)  # 'mode' switch, the additional momentary switch
isoswitch = Pin(22, mode=Pin.IN, pull = Pin.PULL_UP)  # 'iso' switch, the additional momentary switch
outA = Pin(6, mode=Pin.IN, pull = Pin.PULL_UP)        # Pin CLK of encoder
outB = Pin(7, mode=Pin.IN, pull = Pin.PULL_UP)        # Pin DT of encoder
ledPin = Pin(25, mode = Pin.OUT, value = 0)           # Onboard led on GPIO 25

# Power Management
vsys = ADC(29)                                        # reads the system input voltage
charging = Pin(24, Pin.IN)                            # reading GP24 tells us whether or not USB power is connected
conversion_factor = 3 * 3.3 / 65535

full_battery = 4.2                  # these are our reference voltages for a full/empty battery, in volts
empty_battery = 2.8                 # the values could vary by battery size/manufacturer so you might need to adjust them

def battery_percentage():
    voltage = vsys.read_u16() * conversion_factor
    return percentage_from_voltage(voltage, empty_battery, full_battery)

utime.sleep(.3)                     # wait until the pico is fully powered up
percentage = battery_percentage()

# setup screen
height = 128                         # the height of the oled
spi = SPI(0,
                  baudrate=10000000,
                  polarity=1,
                  phase=1,
                  bits=8,
                  firstbit=SPI.MSB,
                  sck=psck,
                  mosi=pmosi)
ssd = SSD(spi, pcs, pdc, prst, height)  # Create a display instance

# Attach interrupt to Pins
# attach interrupt to the outA pin ( CLK pin of encoder module )
outA.irq(trigger = Pin.IRQ_RISING | Pin.IRQ_FALLING,
              handler = encoder)

# attach interrupt to the outB pin ( DT pin of encoder module )
outB.irq(trigger = Pin.IRQ_RISING | Pin.IRQ_FALLING ,
              handler = encoder)

# attach interrupt to the switch pin ( SW pin of encoder module )
switch.irq(trigger = Pin.IRQ_FALLING ,
           handler = button)

# attach interrupt to the switch pin ( SW pin of mode switch )
modeswitch.irq(trigger = Pin.IRQ_FALLING ,
           handler = modebutton)

# attach interrupt to the switch pin ( SW pin of iso switch )
isoswitch.irq(trigger = Pin.IRQ_FALLING ,
           handler = isobutton)

# define global variables
outA_last = 0 # registers the last state of outA pin / CLK pin
outA_current = 0 # registers the current state of outA pin / CLK pin

button_last_state = False # initial state of encoder's button 
button_current_state = "" # empty string ---> current state of button
modebutton_last_state = False # initial state of encoder's button 
modebutton_current_state = "" # empty string ---> current state of button
isobutton_last_state = False # initial state of encoder's button 
isobutton_current_state = "" # empty string ---> current state of button

# Read the last state of CLK pin in the initialisaton phase of the program 
outA_last = outA.value() # lastStateCLK

# End Hardware ###################################################################################


# Main Logic
# Values for Fstop, Shutter Speed and ISO (ascending brightness)
fstops= [260,180,161, 144, 128, 114, 102, 90, 81, 72, 64, 57, 51, 45, 40, 36, 32, 29, 25, 22, 20, 18, 16, 14, 13, 11, 10, 9, 8, 7.1, 6.3, 5.6, 5, 4.5, 4, 3.6, 3.2, 2.8, 2.5, 2.2, 2, 1.8, 1.6, 1.4, 1.3, 1.1, 1, 0.9, 0.8, 0.7, 0.6]
sspeed= ["(1/ 8000)","(1/ 6400)","(1/ 5000)","(1/ 4000)","(1/ 3200)","(1/ 2500)","(1/ 2000)","(1/ 1600)","(1/ 1250)","(1/ 1000)","(1/ 800)","(1/ 640)","(1/ 500)","(1/ 400)","(1/ 320)","(1/ 250)","(1/ 200)", "(1/ 160)","(1/ 125)","(1/ 100)","(1/ 80)","(1/ 60)","(1/ 50)","(1/ 40)","(1/ 30)","(1/ 25)","(1/ 20)","(1/ 15)","(1/ 13)","(1/ 10)","(1/ 8)","(1/ 6)","(1/ 5)","(1/ 4)","0.3","0.4","0.5","0.6","0.8","1","1.3","1.6","2","2.5","3.2","4","5","6","8","10","13","15","20","25","30","40","50","60","70","80","90","100","110","120","130","140","150","160","170","180","190","200","250","300","350","400","450","500","600","700","800","900","1000","1500","2000","2500","3000"]
isonum= [.5,1,2,3,4,5,6,8,10,12,16,20,25,32,40,50,64,80,100,125,160,200,250,320,400,500,640,800,1000,1250,1600,2000,2500,3200, 4000, 5000,6400,8000]
modes= ["AmbientShutterSpeed","AmbientAperture"]
try:
    f = open('lastisoindex.txt', "r")
    isoindex = int(f.read())
    f.close()
except:
    print('no isoindex file..... using default')
    isoindex = 18                        # Default: ISO 100
evcorrection = 0                   # A stop adjustment for EV. Set using greycard and Nikond850
                                     # (additive implies a proportional relationship between brightness and lux, check maths)
calibrationconst=15
mode=modes[1]                        # Default: AmbientAperture mode
apertureindex = 26                   # Default: f/8 ('f8 and be there' - Weegee)
isoadjust=False
pin=0
counter= 0
lastcounter=0
lastupdate = utime.time()  
red, green, blue, lastmeasure=sensorread()
speedindex = otherindex(apertureindex, isoindex, mode, lastmeasure)
gc.enable()                          # enable garbage collection
refresh(ssd, True)                   # Initialise and clear display.
splash('photon')

while True:
    iso=isonum[isoindex]
    speed=sspeed[speedindex]
    aperture=fstops[apertureindex]
    encoder(pin)   
    if counter!=lastcounter or button_current_state != button_last_state:
    # adjust aperture or shutter speed, depending on mode selected
        if isoadjust:
            isoindex=isoindex + counter
            isoindex=max(0,isoindex)
            isoindex=min(len(isonum)-1,isoindex)
        if mode=="AmbientAperture":
            if not isoadjust:
                apertureindex=apertureindex + counter
                apertureindex=max(0,apertureindex)
                apertureindex=min(len(fstops)-1,apertureindex)
            # Now, derive shutter speed from aperture choice and lastmeasure
            speedindex = otherindex(apertureindex, isoindex, mode, lastmeasure)
        elif  mode=='AmbientShutterSpeed':
            if not isoadjust:
                speedindex=speedindex + counter
                speedindex=max(0,speedindex)
                speedindex=min(len(sspeed)-1,speedindex)
            # Now, derive aperture from shutter speed choice and lastmeasure
            apertureindex = otherindex(speedindex, isoindex, mode, lastmeasure)
        counter=0
        displaynum(aperture, speed, iso,mode, isoadjust,lastmeasure, red,green,blue)
    lastcounter=counter
    button_last_state = False     # reset button last state to false again ,
                                  # can also be done from other subroutines
                                  # or from the main loop
    modebutton_last_state = False # see above
    isobutton_last_state = False  # see above
    gc.collect()                  # force garbage collect
    now = utime.time()

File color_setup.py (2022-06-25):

import machine
import gc
from drivers.ssd1351.ssd1351 import SSD1351 as SSD

height = 128  # height = 128 # 1.5 inch 128*128 display

pdc = machine.Pin(20, machine.Pin.OUT, value=0)
pcs = machine.Pin(17, machine.Pin.OUT, value=1)
prst = machine.Pin(21, machine.Pin.OUT, value=1)
spi = machine.SPI(0,
                  baudrate=10000000,
                  polarity=1,
                  phase=1,
                  bits=8,
                  firstbit=machine.SPI.MSB,
                  sck=machine.Pin(18),
                  mosi=machine.Pin(19),
                  miso=machine.Pin(16))
gc.collect()  # Precaution before instantiating framebuf
ssd = SSD(spi, pcs, pdc, prst, height)  # Create a display instance

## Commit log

2022-06-25 addred (too many) drivers
2022-06-26 Update main.py
    Encoder works, oled works, light levels being read
2022-06-26 Next step.... workflow and calibration
2022-07-01 Added calibration to EV
2022-07-02 Moved Rotary Encoder Pins
2022-07-03 Added Battery Charge to Splash Screen
2022-07-03 dirsctory for enclosure stls
2022-07-04 Added Op Amp, tweaked calibration
2022-07-04 Switch to BH1745
2022-07-11 better button treatment
2022-07-11 Stop math error in the far
    [main.py]
2022-07-11 switching to uasyncio, not working yet
    [main.py]
2022-07-11 Back to interrupts for now
2022-07-11 swapped measure and mode buttons
    [main.py]
2022-10-09 Tweak calibration post-build
2022-10-09 Initial add, see Readme'
    [firstframe.stl]
2022-10-14 checked maths before greycard calibration
2022-10-14 Added Light Meter Calibration constant
2022-12-07 Readme for Pico LiPo case
2022-12-07 Photos for Pico Lipo case
2022-12-07 Mention battery
2022-12-07 STL files
    [back.stl, front.stl, lumisphere.stl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]
2022-12-07 tidy structure
    [firstframe.stl]
2022-12-07 Minor fixes to the back and case
    [back.stl]
2023-01-11 Fixed screw size in documentation
2023-01-31 Wait 0.3 sec before reading the battery level
2024-06-05 Extended range for Exposure and Aperture
    I added some settings to the exposure and the aperture to extended those possibilities.
    You can now go up to 3000s long and f/260.
    I work with an Ultra large lens: exposure are long and aperture narrow !
2024-08-18 new shell
    [case.stl]
2024-08-26 Screw tweak
    [case.stl]
2026-09-05 Add Pico uploader and battery status

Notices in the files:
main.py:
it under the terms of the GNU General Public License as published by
